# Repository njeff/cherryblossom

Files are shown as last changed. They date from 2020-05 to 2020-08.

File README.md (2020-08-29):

Cherry Blossom Numpad
=====

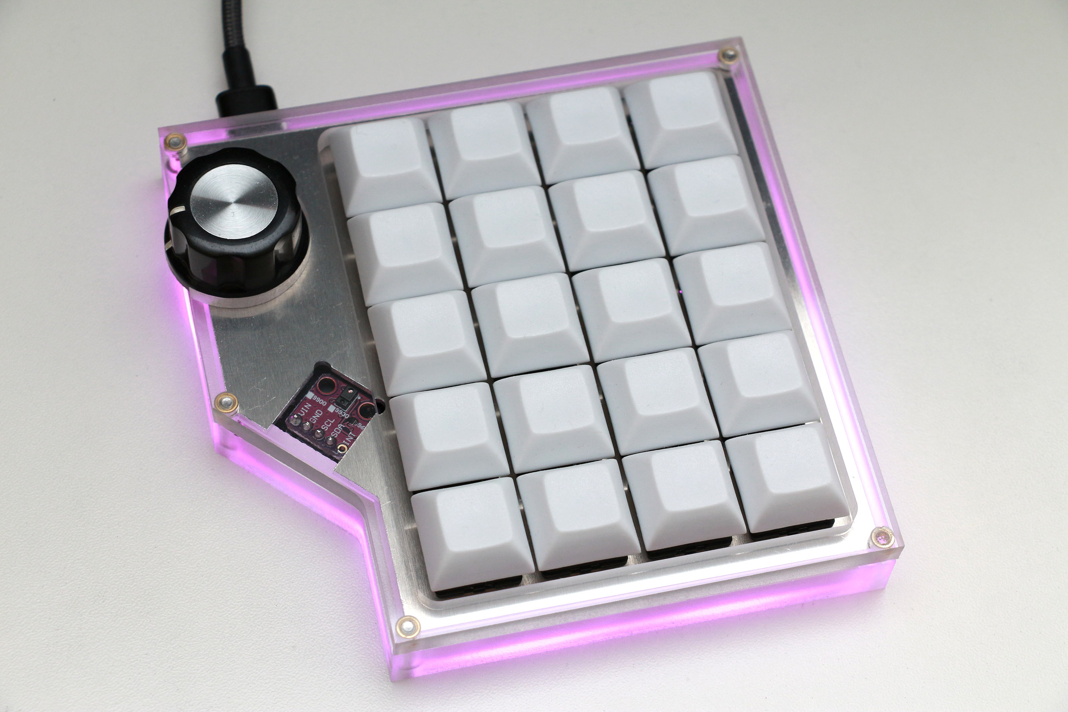
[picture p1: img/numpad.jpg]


A custom DIY numpad. See the build process and it in action [here](https://youtu.be/7neqXtf0uJI).

Features:
 - RGB Backlighting with APA102
 - Encoder side wheel with push button
 - Support for 17 or 20 key layouts
 - Gesture sensor (APDS-9960)
 - QMK powered

The APDS-9960 gesture sensor can detect proximity, brightness, color, or gestures. Gestures consist of up, down, left, right, close and far. Using the gesture detection is currently a little finicky because if there is a gesture being performed over the sensor (or really any movement over the sensor) the numpad is unresponsive to all button inputs.

PCB gerbers, schematic, and BOM are in the `pcb` folder. The BOM has the Mouser numbers for the parts I ordered (The unfilled in parts numbers are not there because I had those on hand. The USB-C connector came from eBay; look for the ones that only have a single row of pins. The six pin programming header is only needed if you somehow are unable to program over USB.).

A couple of things to look out for when building this:
 - The footprint for the diodes are pretty much exact fits for the diode, which makes soldering by hand rather difficult (reflow is okay). If I make a revision this will be updated.
 - The USB-C connector being on top means that if you solder the switches in the plate flush to the PCB, there may not be enough clearance between the USB cable you use and the plate. I soldered the switches so the legs of the switches barely pop out of the PCB holes. A new revision would have the USB-C connector on the bottom of the PCB.
 - You need small jumper wires when soldering the floating legs of the encoder to the PCB. A revision will move the pads to the edge of the PCB for direct soldering.
 - The case may need some changes to the USB-C connector hole. It seems to work for the prototypes I made, but I also had some strange manufacturing issues specific to my process.
 - I don't have the time right now to make the changes for the revision and test it.

One day if I get the time and there is interest I could put together a kit.

A 3D model of the case and plate without the gesture sensor hole is in the model folder called `numpad_nogesture.step`. If you want the hole for the gesture sensor, use the model `numpad_gesture.step`. The body thicknesses are slightly different because they came from different models where I had different material thicknesses set for CNC operations.

The firmware for the numpad is under my personal fork of the QMK firmware.

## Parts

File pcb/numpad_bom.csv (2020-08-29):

Ref | Qnty | Value | Cmp name | Footprint | Description | Vendor | Mouser
C1, C2, | 2 | 10p | C | Capacitor_SMD:C_0603_1608Metric | Unpolarized capacitor |  | 581-06035A100J
C3, C5, | 2 | 1u | C | Capacitor_SMD:C_0603_1608Metric | Unpolarized capacitor |  | 603-CC603KRX5R8BB105
C4, C7, C8, C9, C10, C11, C12, C13, C14, C15, | 10 | 0.1u | C | Capacitor_SMD:C_0603_1608Metric | Unpolarized capacitor
C6, | 1 | 10u | C | Capacitor_SMD:C_0603_1608Metric | Unpolarized capacitor |  | 581-0603ZD106KAT2A
D1, | 1 | LED | LED | LED_SMD:LED_0603_1608Metric | Light emitting diode |  | 710-150060YS55040
D2, D7, D12, D17, D13, D8, D3, D18, D4, D9, D14, D19, D15, D10, D5, D20, D16, D11, D6, D21, | 20 | D | D | Diode_SMD:D_SOD-323 | Diode |  | 863-BAS16HT1G
D22, D23, D24, D25, D26, D27, D28, D29, D30, | 9 | APA102C_5050 | APA102C_5050 | LED_SMD:LED_RGB_5050-6 | APA102C Addressable LED
F1, | 1 | Polyfuse | Polyfuse | Fuse:Fuse_1206_3216Metric | Resettable fuse, polymeric positive temperature coefficient |  | 504-PTS120615V050
J1, | 1 | USB_C_Receptacle_USB2.0 | USB_C_Receptacle_USB2.0 | personal_f:USB_C_16P | USB 2.0-only Type-C Receptacle connector
J2, | 1 | AVR-ISP-6 | AVR-ISP-6 | Connector_PinHeader_2.54mm:PinHeader_2x03_P2.54mm_Vertical_SMD | Atmel 6-pin ISP connector
J4, J3, | 2 | Conn_01x01 | Conn_01x01 | Connector_PinHeader_2.54mm:PinHeader_1x01_P2.54mm_Vertical | Generic connector, single row, 01x01, script generated (kicad-library-utils/schlib/autogen/connector/)
J5, | 1 | Conn_01x04 | Conn_01x04 | Connector_PinHeader_2.54mm:PinHeader_1x04_P2.54mm_Vertical | Generic connector, single row, 01x04, script generated (kicad-library-utils/schlib/autogen/connector/)
R2, R1, | 2 | 22 | R | Resistor_SMD:R_0603_1608Metric | Resistor |  | 71-CRCW060322R0FKEAC
R3, R5, R9, R8, | 4 | 10k | R | Resistor_SMD:R_0603_1608Metric | Resistor
R4, | 1 | 1k | R | Resistor_SMD:R_0603_1608Metric | Resistor
R7, R6, | 2 | 5.1k | R | Resistor_SMD:R_0603_1608Metric | Resistor |  | 71-CRCW06035K10FKEAC
SW1, | 1 | Rotary_Encoder_Switch | Rotary_Encoder_Switch | personal_f:EC12D15_Encoder_With_Pushbutton | Rotary encoder, dual channel, incremental quadrate outputs, with switch |  | 688-EC12D1524403
SW2, | 1 | SW_SPST | SW_SPST | Button_Switch_SMD:SW_SPST_SKQG_WithStem | Single Pole Single Throw (SPST) switch |  | 688-SKQGAKE010
SW3, SW8, SW13, SW18, SW4, SW9, SW14, SW19, SW5, SW10, SW15, SW20, SW6, SW11, SW16, SW21, SW7, SW12, SW17, SW22, | 20 | SW_SPST | SW_SPST | Button_Switch_Keyboard:SW_Cherry_MX_1.00u_PCB | Single Pole Single Throw (SPST) switch
SW23, | 1 | SW_SPST | SW_SPST | Button_Switch_Keyboard:SW_Cherry_MX_2.00u_PCB | Single Pole Single Throw (SPST) switch
SW25, SW24, | 2 | SW_SPST | SW_SPST | personal_f:SW_Cherry_MX_2.00u_Vertical_PCB_Flip | Single Pole Single Throw (SPST) switch
U1, | 1 | ATmega32U4-AU | ATmega32U4-AU | Package_QFP:TQFP-44_10x10mm_P0.8mm | 16MHz, 32kB Flash, 2.5kB SRAM, 1kB EEPROM, USB 2.0, TQFP-44 |  | 556-ATMEGA32U4-AU
Y1, | 1 | 16MHz | Crystal_GND24 | Crystal:Crystal_SMD_EuroQuartz_MT-4Pin_3.2x2.5mm | Four pin crystal, GND on pins 2 and 4 |  | 732-TX325-16F09Z-AC3

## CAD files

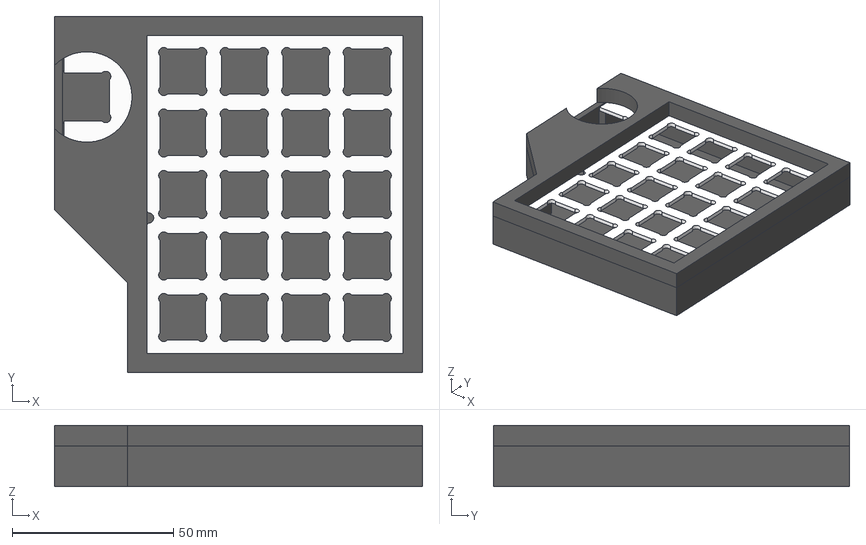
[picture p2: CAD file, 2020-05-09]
models/numpad_gesture.step
114.0 x 110.4 x 19.1 mm
plate
top

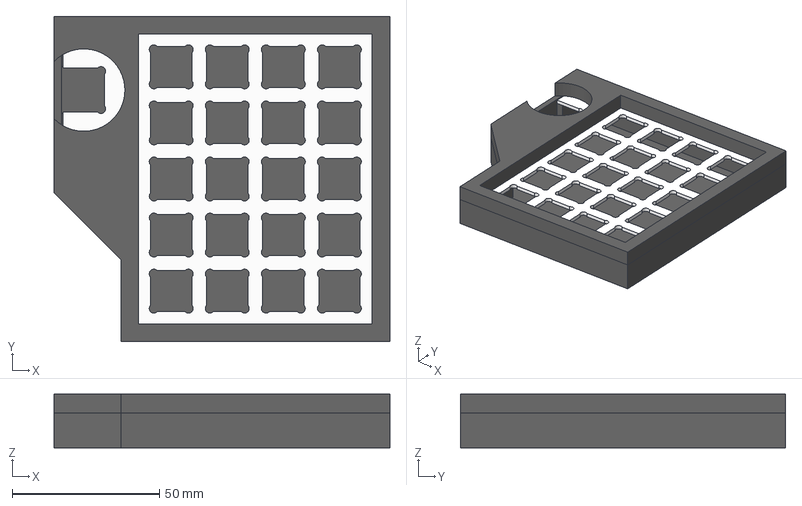
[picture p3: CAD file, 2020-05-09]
models/numpad_nogesture.step
114.0 x 110.4 x 18.2 mm
plate
top

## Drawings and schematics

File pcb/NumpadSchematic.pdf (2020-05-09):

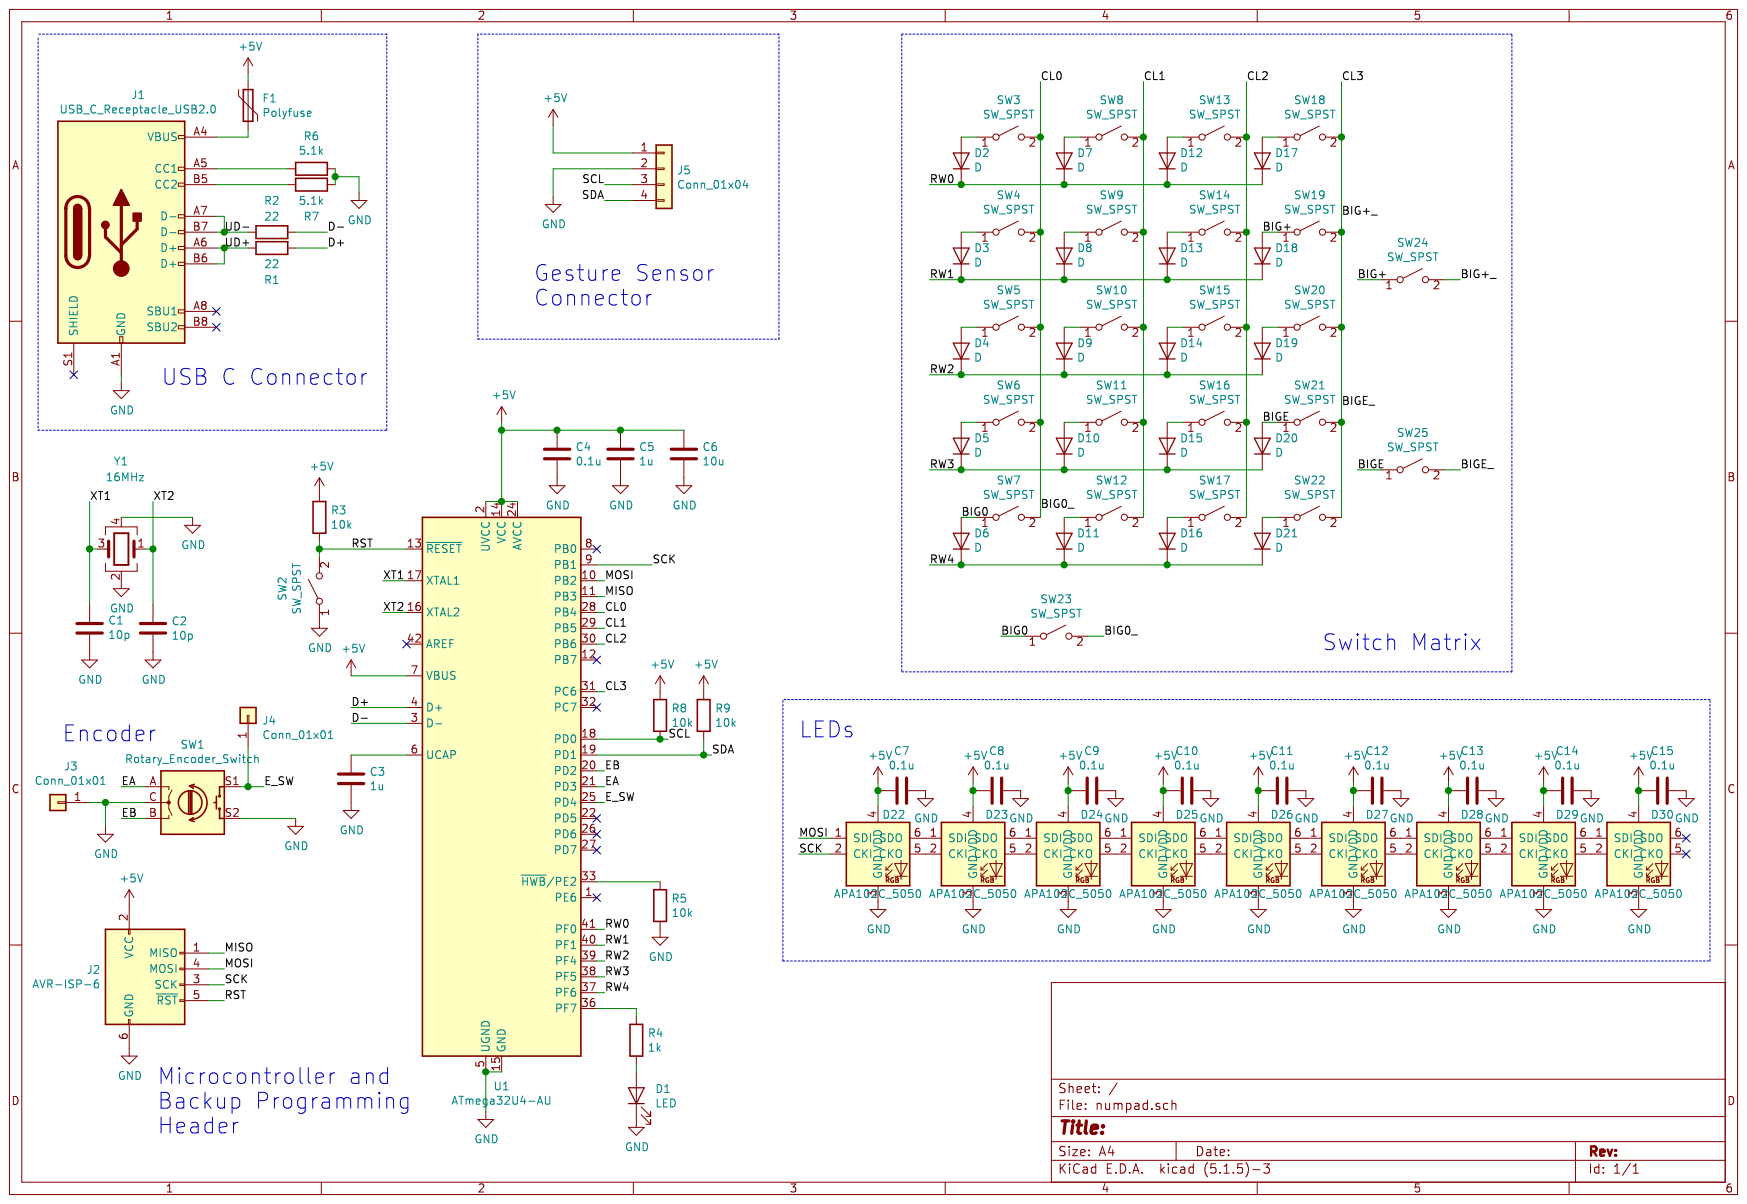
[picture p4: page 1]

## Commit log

2020-05-09 Intial release
    [numpad_gesture.step, numpad_nogesture.step]
2020-08-29 Add BOM
    [numpad_bom.csv]
